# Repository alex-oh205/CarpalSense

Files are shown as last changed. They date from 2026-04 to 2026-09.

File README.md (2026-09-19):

# CarpalSense

Wearable sensor project made by Alex Oh and Arjun ArunPrasad on the software side and Shiv Patel and Kanata Sasaki on the hardware side.

Hardware: A glove that detects and monitors carpal tunnel syndrome using flex sensors, EMG sensors, and an Arduino Nano.
Software: The CarpalSense website, containing detailed usage instructions and a real-time monitoring dashboard displaying the collected data.

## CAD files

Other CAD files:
bme_materials/CarpalSense Glove (Final Product).f3z

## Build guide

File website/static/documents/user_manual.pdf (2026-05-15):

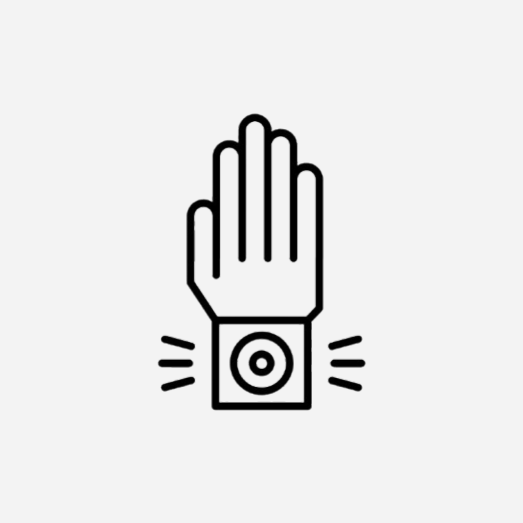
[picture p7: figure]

# CarpalSense Instruction Manual

## Group 3 Wearable Sensor

### Made By: Shiv Patel, Kanata Sasaki, Arjun Arun-Prasad, Alex Oh

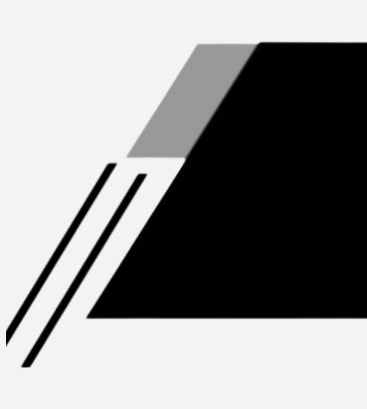
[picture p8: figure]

## Page 01

# Table of Contents

❖Procedure | —--------------------- Page 03
❖Circuit Design | —--------------------- Page 08
❖Fusion Models | —--------------------- Page 09
❖Data | —--------------------- Page 10
➢Flex | —--------------------- | Page 10
➢EMG | —--------------------- Page 11
❖Troubleshooting | —--------------------- Page 12
➢Flex | —--------------------- | Page 12
➢EMG | —--------------------- Page 13

# Procedure

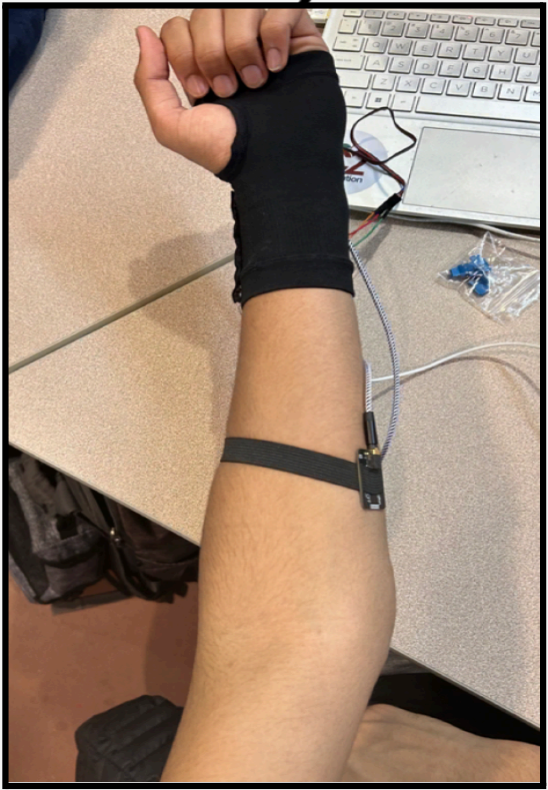
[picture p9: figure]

## Place the EMG sensor on your forearm using the band attached to it. Ensure that the cable is facing away from you and that the EMG is placed on the Flexor Pollicis Longus muscle

Note: This step may require multiple attempts due to the abundance of muscles in the forearm; refer to Troubleshooting for further assistance

Figure 01: Example placement of EMG and proper positioning on forearm

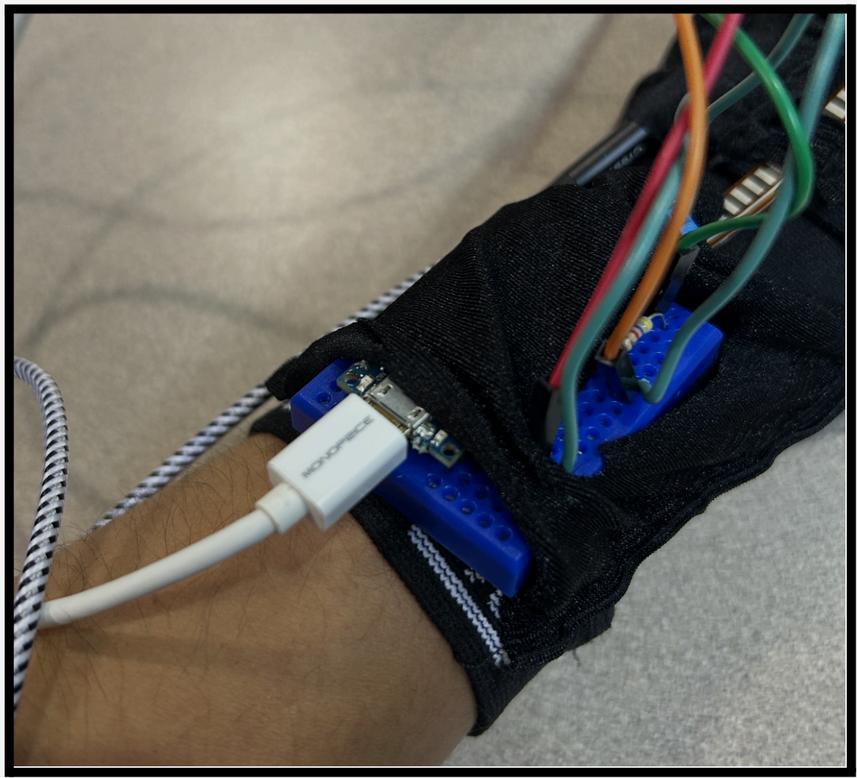
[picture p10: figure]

## Connect a Micro-B to USB cable to the Arduino Nano 33 IOT (located underneath the housing) but do not plug the USB end into the device

being connected.

Figure 02: Micro-B Cable being connected to Arduino Nano

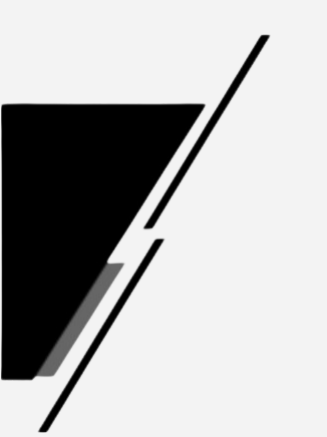
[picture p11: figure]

# Procedure

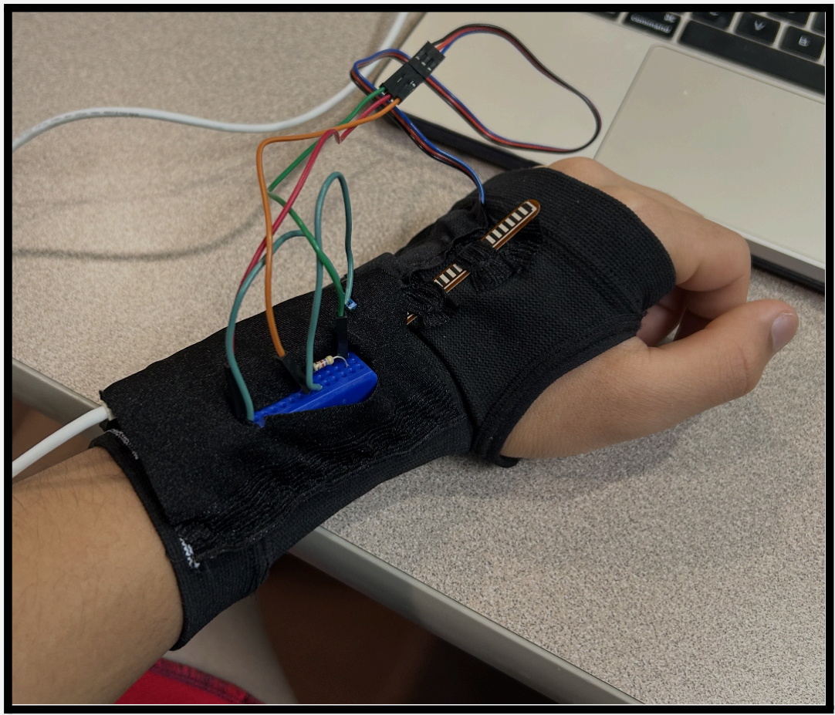
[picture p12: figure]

## Gently pull the glove over your left hand. Make sure that the Arduino 33 Nano IOT and the rest of the circuit are facing up when you do so. Double check all sensor positions before beginning any

data collection.

Figure 03: Wearable sensor fully fitted and worn on the hand.

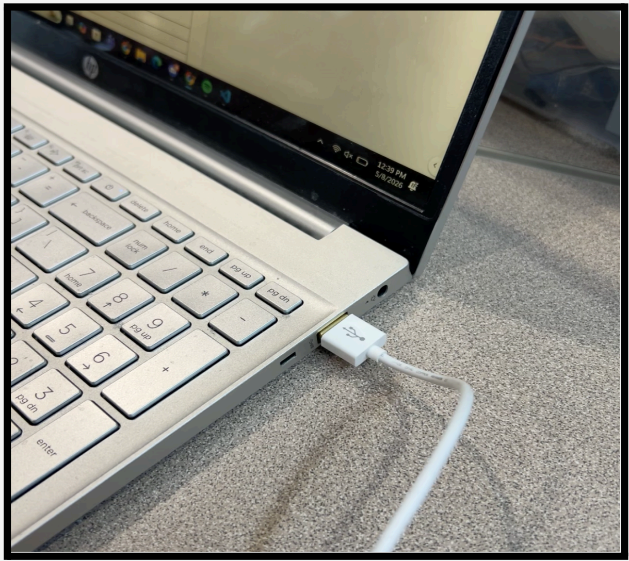
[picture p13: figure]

## Plug in the USB into the computer and place your gloved hand flat on a desk in a flat position for 5-8 seconds. Holding this position will allow the sensor to

calibrate the EMG.

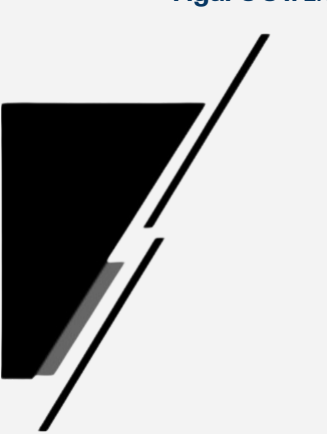
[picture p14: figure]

Figure 04: Example of USB cable connected to a viable device

# Procedure

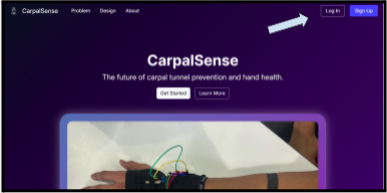
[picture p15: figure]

## Go to the CarpalSense website and log into your account. If you do not have

one, create an account,

## following the prompts given

Figure 05: Homescreen of CarpalSense website with the Log-In page highlighted.

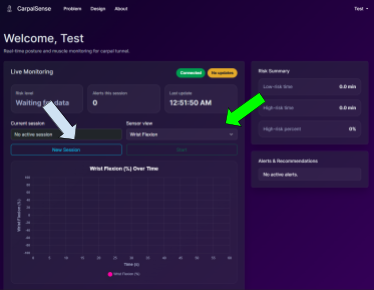
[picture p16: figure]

## Once logged in, select New Session on the Dashboard and click Start to begin collecting data. To toggle which sensor you see, use the drop-down menu

Figure 06: Example Dashboard with the New Session button (blue arrow) and Sensor drop down menu (green arrow) highlighted

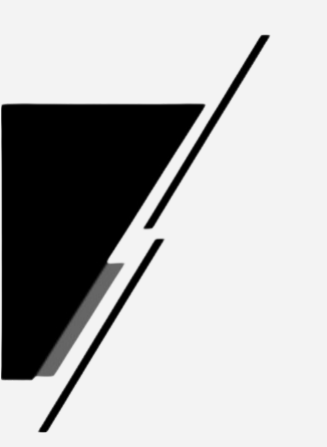
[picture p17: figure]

# Procedure

## After the calibration is complete, all FPL and wrist movement will be monitored and shown on the website via graphs (see Data)

Note: Wrist movements involve bending

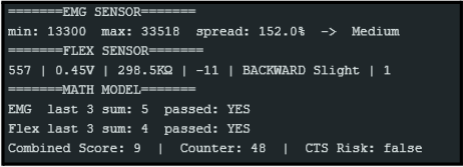
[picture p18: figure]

the wrist forward and backwards and the FPL contractions are monitored by clenching the fist and flexing the muscle

Figure 07: Serial Monitor showing live sensor readings

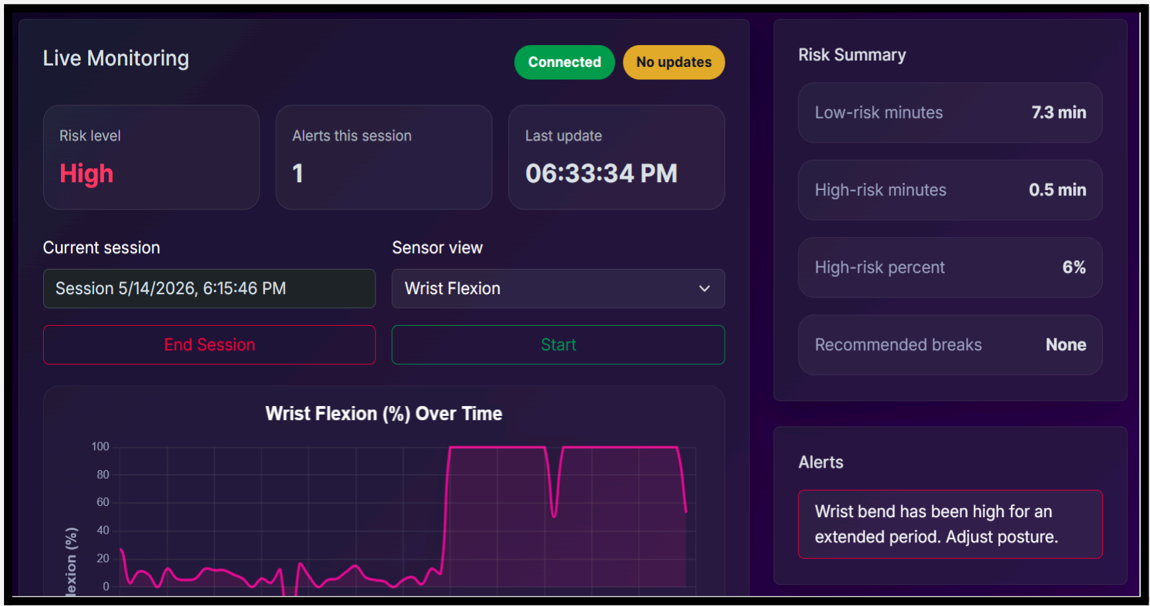
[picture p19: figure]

## If the accumulated strain on the wrist reaches a “danger zone”, a notification will be sent out through the website to tell

you to take a rest.

Figure 08: Alert on website to
show entry into danger zone

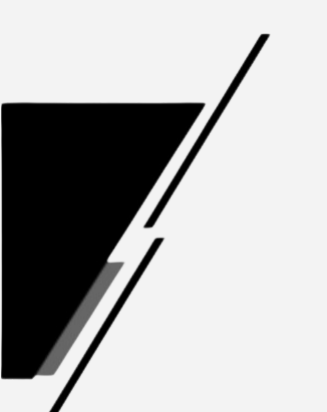
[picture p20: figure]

# Procedure

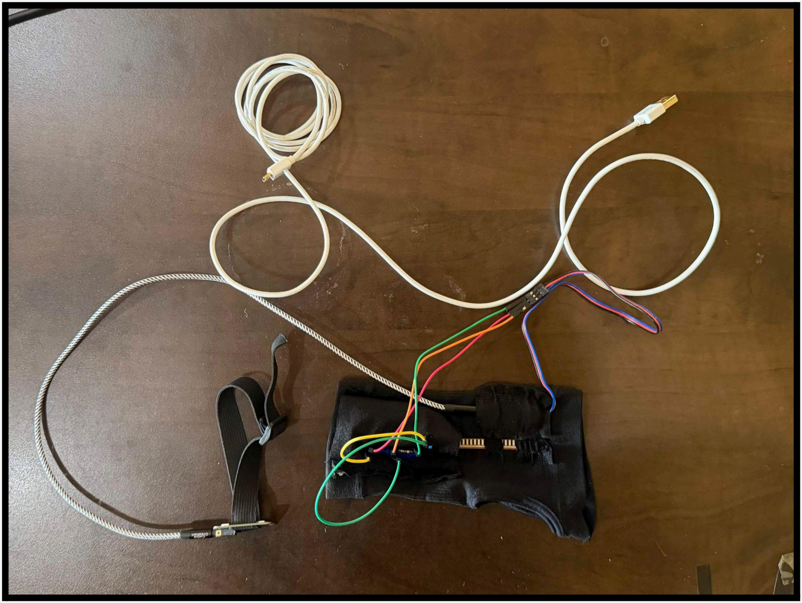
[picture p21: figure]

## To remove the sensor, unplug the Micro-B to USB cable from both ports and then gently remove the glove as well as the Dry EMG band from the forearm. Ensure that no cables are displaced in this process

Figure 09: Safely removed sensor as
well as other components used (cable and band)

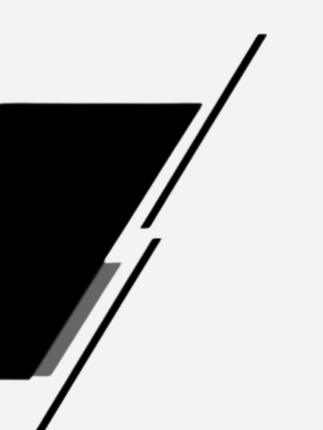
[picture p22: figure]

# Circuit Designs

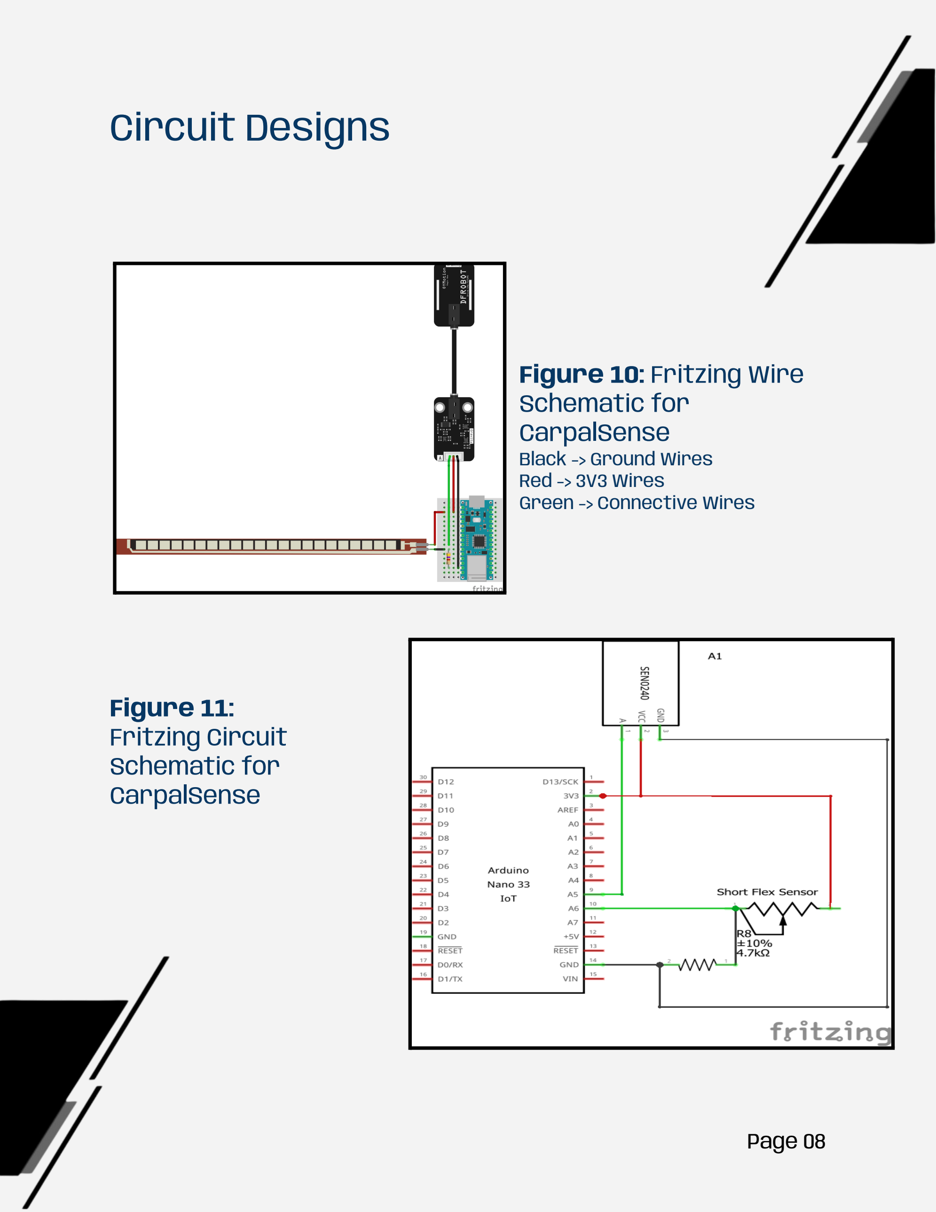
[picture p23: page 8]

## Figure 10: Fritzing Wire Schematic for CarpalSense

### Black -> Ground Wires Red -> 3V3 Wires Green -> Connective Wires

## Figure 11: Fritzing Circuit Schematic for CarpalSense

# Fusion Models

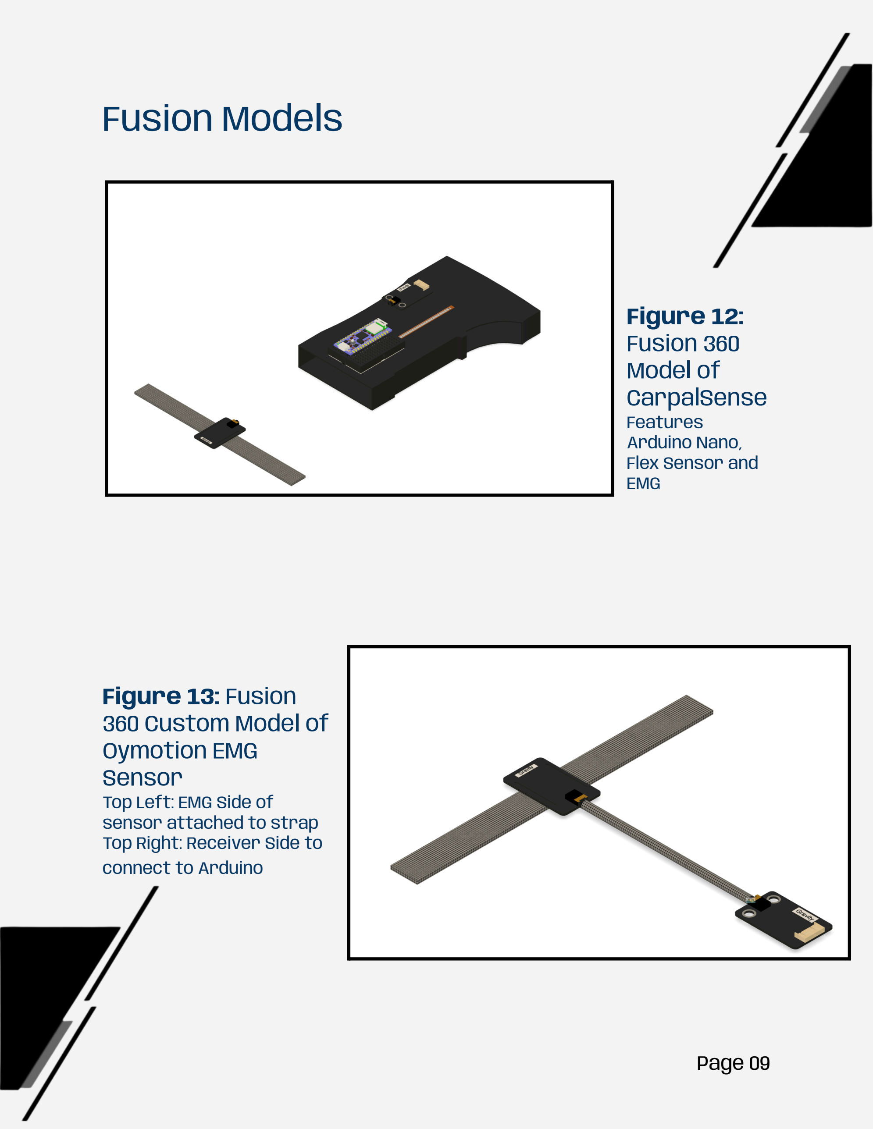
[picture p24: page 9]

## Figure 12: Fusion 360 Model of CarpalSense

### Features

Arduino Nano,

### Flex Sensor and EMG

## Figure 13: Fusion 360 Custom Model of Oymotion EMG Sensor

### Top Left: EMG Side of sensor attached to strap Top Right: Receiver Side to connect to Arduino

# Data

# Flex

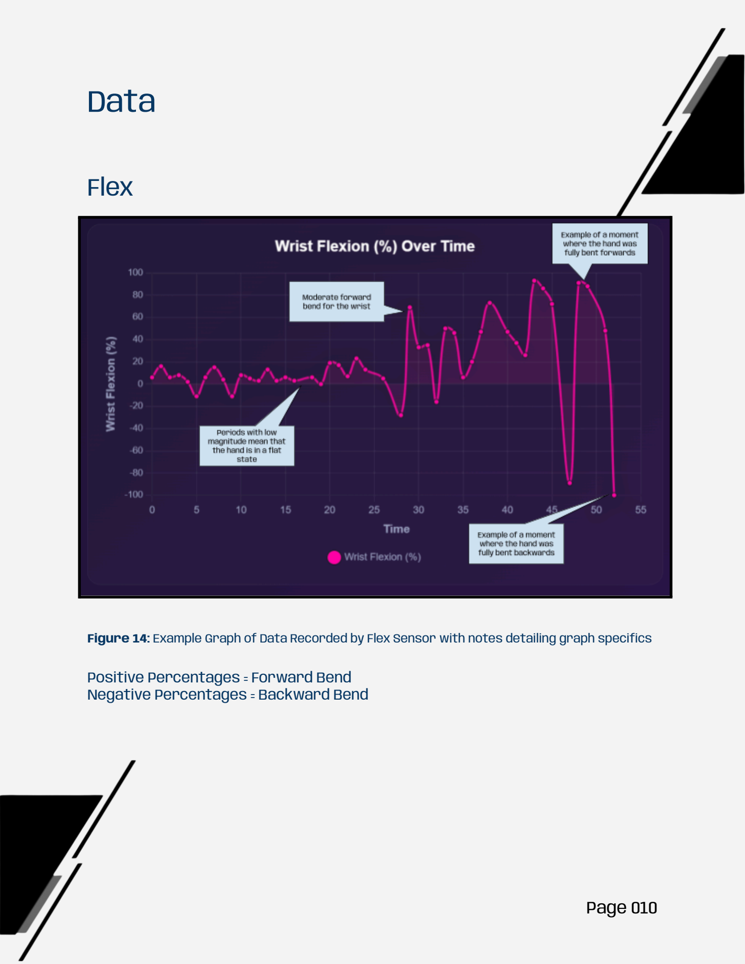
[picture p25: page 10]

Figure 14: Example Graph of Data Recorded by Flex Sensor with notes detailing graph specifics

### Positive Percentages = Forward Bend Negative Percentages = Backward Bend

# Data

# EMG

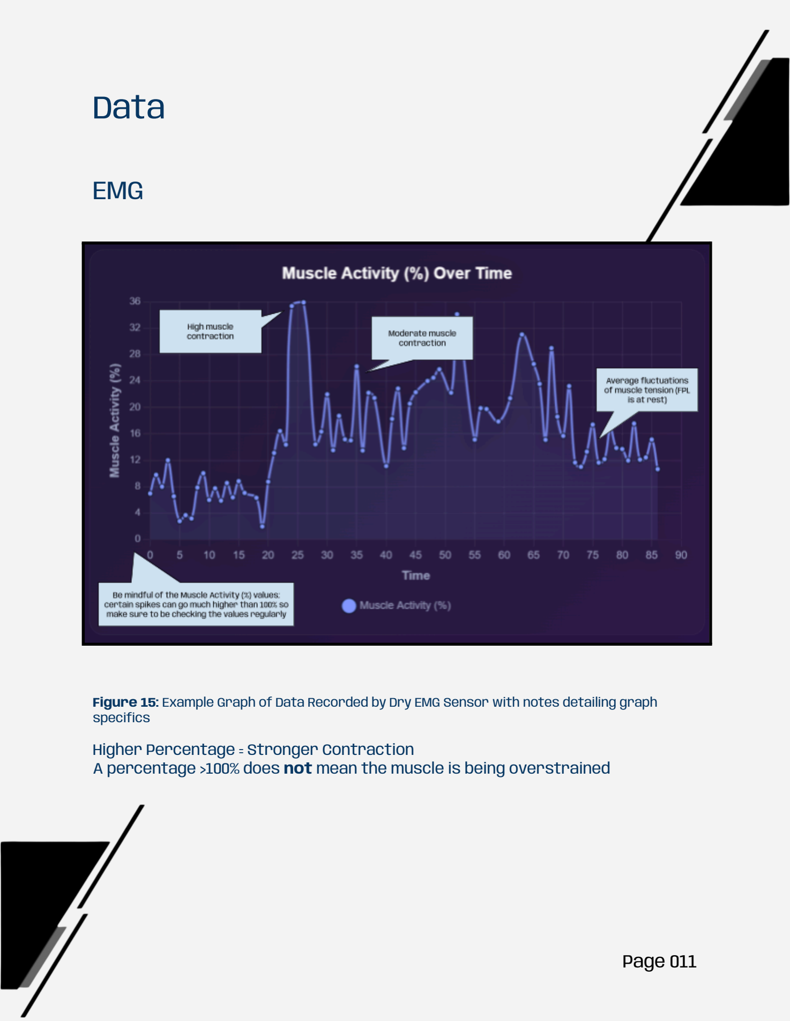
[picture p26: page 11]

Figure 15: Example Graph of Data Recorded by Dry EMG Sensor with notes detailing graph specifics

### Higher Percentage = Stronger Contraction A percentage >100% does not mean the muscle is being overstrained

# Troubleshooting

# Flex

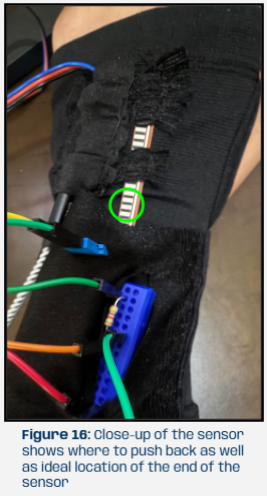
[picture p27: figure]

## ❖Bending not recording

### - Double check all wires and make sure they are connected

■ Wires will connect to the Clinch Connector inside of the housing, not the flex sensor itself

### - Check the flex sensor’s position

■ The end of the sensor should be pushed as far in as it can go.
■ If the sensor is not fully pushed in, gently push it further in at the position specified by the green circle on Figure 15.

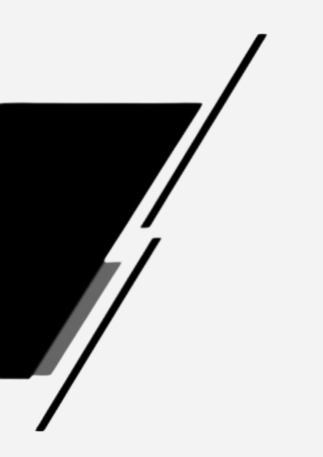
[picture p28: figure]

# Troubleshooting

# EMG

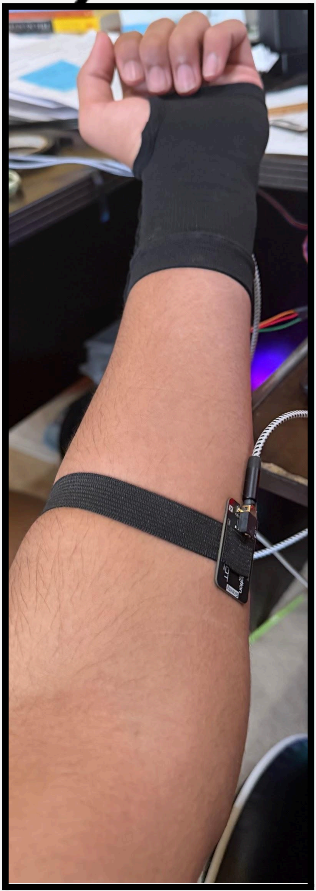
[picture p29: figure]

## ❖Contractions not recording

### - Check to see if EMG sensor is placed on the right muscle body

■ Place your arm palm up and clench your fist repeatedly ■ Feel along the side of your forearm until you find a muscle that is tensing with your forearm. Place EMG there.

### - Make sure all wires are connected properly to the sensors - Tighten EMG sensor on the muscle body

## ❖Constantly Returning “High” Contractions

### - Restart the program

■ Unplug the sensor and plug it back in
■ This will recalibrate the baseline

### - Double check EMG placement on the forearm

■ Incorrect placement of the EMG can cause it to read multiple muscles at once or pick up on unnecessary noise ■ View placement directions above

## ❖General Debugging

### - Bicep Check

■ If there are concerns with the EMG sensor, place the
sensor on your bicep and monitor the contractions
following the same procedure as before
■ If the contractions align with bicep motions, it is most likely a placement error
■ If the contractions do not align, check all wires connections to make sure the EMG is properly connected

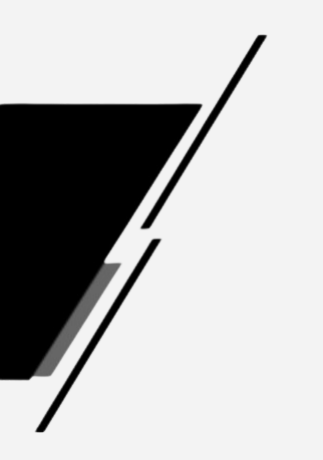
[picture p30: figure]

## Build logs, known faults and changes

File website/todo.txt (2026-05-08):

- Change Firebase data structure to include date/time
- Make it so you can select a date/time to view its data
- Footer

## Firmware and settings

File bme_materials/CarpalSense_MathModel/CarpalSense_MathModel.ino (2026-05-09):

// ============================================================
// CarpalSense — Full Integrated Math Model
// Arduino Nano 33 IoT
//
// SENSORS:
//   Flex sensor → A6
//   EMG sensor  → A5
//
// OUTPUT:
//   Serial Monitor only (no buzzer)
//
// WHAT THIS DOES:
//   1. Reads flex sensor → converts to 0-3 score
//   2. Calibrates EMG baseline on startup (30 seconds)
//   3. Reads EMG sensor → converts to 0-3 score
//   4. Combines both into Cumulative Strain Score (CSS)
//   5. Prints full dashboard to Serial Monitor every second
//
// SCIENTIFIC BASIS:
//   Flex thresholds: 25mmHg carpal tunnel pressure research
//     Forward (flexion)  danger at 38° → position ~+65
//     Backward (extension) danger at 27° → position ~-50
//   EMG thresholds: intramuscular pressure research
//     4x resting baseline ≈ 25% MVC ≈ 21mmHg pressure
//   CSS weights: force (EMG) weighted higher than posture (flex)
//     based on pooled study of 2,474 workers
//   CSS thresholds: Revised Strain Index clinical research
//     Safe < 8.5, Caution 8.5-15, Warning 15-20, Danger > 20
// ============================================================


// ============================================================
// FLEX SENSOR SETUP
// Copied directly from your existing code
// ============================================================
const int   FLEX_PIN    = A6;
const float VCC         = 3.3;
const float R_DIV       = 47000.0;

// Your calibrated raw values — keep these as they are
int rawFlat     = 22;
int rawForward  = 7;
int rawBackward = 40;

const int DEADZONE = 2;

// ------------------------------------------------------------
// FLEX POSITION THRESHOLDS
// These are in "position" units (-100 to +100) from your code
//
// FORWARD  = wrist flexion  (danger at 38°)
// BACKWARD = wrist extension (danger at 27°)
//
// Your position scale goes 0 to 100 for full bend.
// 38° flexion is roughly 65% of your full forward range.
// 27° extension is roughly 50% of your full backward range.
//
// So in position units:
//   Forward  warn    = +40   (approaching 38° flexion)
//   Forward  danger  = +65   (at 38° flexion)
//   Backward warn    = -35   (approaching 27° extension)
//   Backward danger  = -50   (at 27° extension)
//
// IF THESE FEEL WRONG after testing, adjust them here.
// ------------------------------------------------------------
const int FLEX_FWD_WARN    =  40;
const int FLEX_FWD_DANGER  =  65;
const int FLEX_BWD_WARN    = -35;
const int FLEX_BWD_DANGER  = -50;


// ============================================================
// EMG SENSOR SETUP
// ============================================================
const int EMG_PIN = A5;

// Calibration
const int CALIBRATION_SECONDS = 30;
float     emgBaseline         = 0.0;
bool      calibrated          = false;

// EMG ratio thresholds (multiples of resting baseline)
// 2x = light sustained effort  (~5% MVC)
// 3x = moderate effort         (~10-15% MVC)
// 4x = high effort             (~20-25% MVC)
//      Research: 25% MVC produces 21mmHg intramuscular pressure
//      approaching your 25mmHg clinical CTS threshold
const float EMG_LEVEL_1 = 2.0;
const float EMG_LEVEL_2 = 3.0;
const float EMG_LEVEL_3 = 4.0;


// ============================================================
// CSS (CUMULATIVE STRAIN SCORE) SETUP
// Thresholds from Revised Strain Index clinical research
// validated on 1,372 workers followed for up to 6 years
// ============================================================
float css = 0.0;

const float CSS_CAUTION  =  8.5;
const float CSS_WARNING  = 15.0;
const float CSS_DANGER   = 20.0;

// Weights — EMG carries more weight than flex
// Scientific basis: forceful exertion is a stronger
// independent predictor of CTS than wrist posture alone
const float EMG_WEIGHT   = 0.6;
const float FLEX_WEIGHT  = 0.4;

// Recovery rate when both sensors read 0
// Muscles recover slowly — not instant
const float RECOVERY_RATE = 0.1;


// ============================================================
// TIMING
// ============================================================
unsigned long previousMillis = 0;
const long    INTERVAL       = 1000; // update every 1 second


// ============================================================
// SETUP
// ============================================================
void setup() {
  Serial.begin(9600);
  while (!Serial);

  pinMode(FLEX_PIN, INPUT);

  Serial.println("============================================");
  Serial.println("        CarpalSense Starting Up            ");
  Serial.println("============================================");

  // Run EMG calibration before anything else
  calibrateEMG();
}


// ============================================================
// MAIN LOOP
// ============================================================
void loop() {
  unsigned long currentMillis = millis();

  if (currentMillis - previousMillis >= INTERVAL) {
    previousMillis = currentMillis;

    // 1. Get flex position and score
    int flexPosition = getFlexPosition();
    int flexScore    = getFlexScore(flexPosition);

    // 2. Get EMG score
    int emgScore = getEMGScore();

    // 3. Update CSS
    updateCSS(flexScore, emgScore);

    // 4. Print full dashboard
    printDashboard(flexScore, emgScore, flexPosition);
  }
}


// ============================================================
// EMG CALIBRATION
// Runs once on startup for 30 seconds.
// User must rest hand flat on desk doing nothing.
// Averages thousands of readings for accurate baseline.
// ============================================================
void calibrateEMG() {
  Serial.println("CALIBRATION STARTING IN 3 SECONDS...");
  Serial.println("Rest your hand flat on the desk. Do not move.");
  delay(3000);
  Serial.println("Calibrating...");

  long  total      = 0;
  int   samples    = 0;
  int   lastPrint  = 0;
  unsigned long startTime = millis();

  while (millis() - startTime < (CALIBRATION_SECONDS * 1000UL)) {
    total += analogRead(EMG_PIN);
    samples++;

    int elapsed = (millis() - startTime) / 1000;
    if (elapsed % 5 == 0 && elapsed != lastPrint && elapsed > 0) {
      Serial.print(CALIBRATION_SECONDS - elapsed);
      Serial.println(" seconds remaining...");
      lastPrint = elapsed;
    }
    delay(10);
  }

  emgBaseline = (float)total / samples;
  calibrated  = true;

  Serial.println("--------------------------------------------");
  Serial.print("Baseline set: ");
  Serial.println(emgBaseline, 1);
  Serial.println("Monitoring started.");
  Serial.println("============================================");
  Serial.println("Flex | EMG | CSS    | Risk");
  Serial.println("============================================");
}


// ============================================================
// FLEX POSITION
// Copied directly from your existing code.
// Returns -100 (full backward) to +100 (full forward)
// ============================================================
int getFlexPosition() {
  int   raw     = analogRead(FLEX_PIN);
  float voltage = raw * (VCC / 1023.0);
  float resistance = 0;

  if (voltage > 0) {
    resistance = R_DIV * (VCC / voltage - 1.0);
  }

  int position = 0;

  if (raw < rawFlat - DEADZONE) {
    // Bending FORWARD (flexion)
    position = constrain(
      (int)((rawFlat - raw) / (float)(rawFlat - rawForward) * 100.0),
      0, 100
    );
  } else if (raw > rawFlat + DEADZONE) {
    // Bending BACKWARD (extension)
    position = constrain(
      (int)((raw - rawFlat) / (float)(rawBackward - rawFlat) * 100.0),
      0, 100
    ) * -1;
  }

  return position;
}


// ============================================================
// FLEX SCORE (0-3)
// Converts position (-100 to +100) into risk score.
//
// Score meaning:
//   0 = neutral, no risk
//   1 = slight bend, minor risk
//   2 = moderate bend, approaching clinical danger angle
//   3 = severe bend, past clinical danger angle
//
// Clinical basis (25mmHg threshold):
//   Flexion danger at 38°   → mapped to position +65
//   Extension danger at 27° → mapped to position -50
// ============================================================
int getFlexScore(int position) {

  // Forward = wrist flexion
  if (position > DEADZONE) {
    if (position >= FLEX_FWD_DANGER) return 3;
    if (position >= FLEX_FWD_WARN)   return 2;
    return 1;
  }

  // Backward = wrist extension
  if (position < -DEADZONE) {
    if (position <= FLEX_BWD_DANGER) return 3;
    if (position <= FLEX_BWD_WARN)   return 2;
    return 1;
  }

  // Neutral
  return 0;
}


// ============================================================
// EMG SCORE (0-3)
// Compares current reading to resting baseline.
//
// Score meaning:
//   0 = at or below baseline (resting)
//   1 = 2x baseline, light sustained effort (~5% MVC)
//   2 = 3x baseline, moderate effort (~10-15% MVC)
//   3 = 4x+ baseline, high effort (~20-25% MVC)
//       At 25% MVC intramuscular pressure reaches 21mmHg
//       approaching your 25mmHg clinical CTS threshold
// ============================================================
int getEMGScore() {
  if (!calibrated) return 0;

  float raw   = analogRead(EMG_PIN);
  float ratio = raw / emgBaseline;

  if (ratio >= EMG_LEVEL_3) return 3;
  if (ratio >= EMG_LEVEL_2) return 2;
  if (ratio >= EMG_LEVEL_1) return 1;
  return 0;
}


// ============================================================
// UPDATE CSS
// Adds weighted sensor scores every second.
// Slowly recovers when both sensors read 0.
//
// Formula every second:
//   CSS += (emgScore x 0.6) + (flexScore x 0.4)
//
// Weight rationale:
//   EMG (force/effort) = stronger CTS predictor
//   Flex (posture)     = real but weaker predictor
//   Source: pooled biomechanical study of 2,474 workers
// ============================================================
void updateCSS(int flexScore, int emgScore) {
  if (flexScore == 0 && emgScore == 0) {
    // Both sensors clear — gradual recovery
    css -= RECOVERY_RATE;
    if (css < 0) css = 0;
  } else {
    float contribution = (emgScore * EMG_WEIGHT) + (flexScore * FLEX_WEIGHT);
    css += contribution;
  }
}


// ============================================================
// PRINT DASHBOARD
// Prints one clean row per second to Serial Monitor.
// Includes direction and zone from your original flex code.
// ============================================================
void printDashboard(int flexScore, int emgScore, int flexPosition) {

  // Flex direction label from your original code
  const char* direction;
  const char* zone;

  if (flexPosition > DEADZONE) {
    direction = "FORWARD ";
    if      (flexPosition < 30) zone = "Slight  ";
    else if (flexPosition < 65) zone = "Moderate";
    else                        zone = "Full    ";
  } else if (flexPosition < -DEADZONE) {
    direction = "BACKWARD";
    if      (flexPosition > -30) zone = "Slight  ";
    else if (flexPosition > -65) zone = "Moderate";
    else                         zone = "Full    ";
  } else {
    direction = "FLAT    ";
    zone      = "        ";
  }

  // Risk level from CSS thresholds
  const char* riskLevel;
  const char* message;

  if (css < CSS_CAUTION) {
    riskLevel = "SAFE   ";
    message   = "All clear.";
  } else if (css < CSS_WARNING) {
    riskLevel = "CAUTION";
    message   = "Strain accumulating. Take a break soon.";
  } else if (css < CSS_DANGER) {
    riskLevel = "WARNING";
    message   = "High strain. Stop and rest now.";
  } else {
    riskLevel = "DANGER ";
    message   = "STOP IMMEDIATELY. Serious CTS risk.";
  }

  // Print full row
  Serial.print("Flex:");
  Serial.print(flexScore);
  Serial.print(" (");
  Serial.print(direction);
  Serial.print(" ");
  Serial.print(zone);
  Serial.print(") | EMG:");
  Serial.print(emgScore);
  Serial.print(" | CSS:");
  Serial.print(css, 2);
  Serial.print(" | ");
  Serial.print(riskLevel);
  Serial.print(" | ");
  Serial.println(message);
}

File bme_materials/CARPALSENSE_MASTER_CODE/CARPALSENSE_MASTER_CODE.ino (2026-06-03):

//  SECTION 1: LIBRARIES AND VARIABLES

// Arduino Libraries
#include "Arduino.h"
#include <limits.h>       // used for window timing
#include "EMGFilters.h"   // needed for EMG code

// Flex Pins
const int   FLEX_PIN = A6;
const float FLEX_VCC = 3.3;
const float FLEX_RES = 47000.0;

// Flex Thresholds
int flexFlat = 550;  // flat value
int flexForward = 400;  // fully bent forward
int flexBackward = 600;  // fully bent backward

const int flexDead = 2;
int returnValue = 0;     // Flex: 0 = None to 3 = High
int level = 0;           // EMG: 0 = No Contraction to 3 = High Contraction

// EMG Pins + RMS
#define SensorInputPin A5
#define RMS_WINDOW 100

long emgBuffer[RMS_WINDOW] = {0};   
int  emgIndex = 0;
long emgRMS = 0;

// EMG Filter
EMGFilters myFilter;
SAMPLE_FREQUENCY sampleRate = SAMPLE_FREQ_500HZ;
NOTCH_FREQUENCY  humFreq    = NOTCH_FREQ_60HZ;

// EMG Thresholds
const unsigned long emgWindow = 1000;  // length of each observation window in milliseconds
const float emgLow = 50.0f;           
const float emgMedium = 100.0f;
const float emgHigh = 200.0f;

unsigned long windowStart = 0;         // Records the time between each EMG return
long windowMin = LONG_MAX;
long windowMax = 0;

// Math Model Values
long ctsCounter = 0;          // total weighted score
const long ctsThreshold = 500000;      // threshold to alert user of CTS risk
bool ctsRisk = false;

int emgMM[3] = {0, 0, 0};   // array of the last 3 readings for EMG
int flexMM[3] = {0, 0, 0};   // array of the last 3 readings for flex
int historyIndex = 0;
bool historyFull = false;
const int valueThreshold = 4; // minimum value of the combined three readings to filter out spikes


//  SECTION 2: SENSOR CODE
// EMG RMS
long computeRMS(long newVal) {        // function is used to smooth out values from EMG sensor
    if (newVal > 200000) newVal = 200000;
    emgRMS -= emgBuffer[emgIndex];
    emgBuffer[emgIndex] = newVal;
    emgRMS += newVal;
    emgIndex = (emgIndex + 1) % RMS_WINDOW;
    return emgRMS / RMS_WINDOW;
}

void setup() {
    // EMG Setup
    analogReference(AR_DEFAULT);
    analogReadResolution(12);
    myFilter.init(sampleRate, humFreq, true, true, true);
    Serial.begin(9600);
    delay(1000);

    for (int i = 0; i < 2000; i++) {          // repeats EMG collection multiple times per loop
        analogRead(SensorInputPin);
        int Value = analogRead(SensorInputPin);
        myFilter.update(Value - 3700);
        delayMicroseconds(2000);
    }

    // Flex Setup
    pinMode(FLEX_PIN, INPUT);     // gathers data from flex
    // Setup Notification
    Serial.println("CTS Master Sensor Code");
    Serial.println("EMG ready. Flex sensor ready.");
    windowStart = millis();
}

void loop() {

    // EMG Data
    analogRead(SensorInputPin);
    int emgRet = analogRead(SensorInputPin);
    int centered  = emgRet - 3700;           // clears out extra noise
    int filtered  = myFilter.update(centered);
    long envelope = (long)filtered * filtered;
    long smoothed = computeRMS(envelope);

    if (smoothed < windowMin) windowMin = smoothed;
    if (smoothed > windowMax) windowMax = smoothed;

    // Flex Data
    int flexRaw = analogRead(FLEX_PIN);
    int flexPosition = 0;
    if (flexRaw < flexFlat - flexDead) {
        flexPosition = constrain(
            (int)((flexFlat - flexRaw) / (float)(flexFlat - flexForward) * 100.0),
            0, 100
        );
    } else if (flexRaw > flexFlat + flexDead) {
        flexPosition = constrain(
            (int)((flexRaw - flexFlat) / (float)(flexBackward - flexFlat) * 100.0),
            0, 100
        ) * -1;
    }

    const char* flexDirection;
    const char* flexBend;

    if (flexPosition > flexDead) {   // uses positive and negative raw values to determine flexion/extension and assigns a value to the returnValue to be used in the math model
        flexDirection = "FORWARD";
        if (flexPosition < 40) { flexBend = "Slight";   returnValue = 1; }
        else if (flexPosition < 75) { flexBend = "Moderate"; returnValue = 2; }
        else { flexBend = "Full";      returnValue = 3; }
    } else if (flexPosition < -flexDead) {    // different values are used for backwards because backwards movement is more strenuous
        flexDirection = "BACKWARD";
        if (flexPosition > -30) { flexBend = "Slight";   returnValue = 1; }
        else if (flexPosition > -55) { flexBend = "Moderate"; returnValue = 2; }
        else { flexBend = "Full";      returnValue = 3; }
    } else {
        flexDirection = "FLAT";
        flexBend      = "";
        returnValue    = 0;
    }

    unsigned long now = millis();
    if (now - windowStart >= emgWindow) {
        float pct = 0.0f;
        if (windowMin > 0) {
            pct = ((float)(windowMax - windowMin) / (float)windowMin) * 100.0f;
            if (pct >= emgHigh) level = 3;
            else if (pct >= emgMedium) level = 2;
            else if (pct >= emgLow)  level = 1;
            else level = 0;
        }

        Serial.println("EMG SENSOR");
        Serial.print("min: " + String(windowMin)); 
        Serial.print("  max: " + String(windowMax)); 
        Serial.print("  spread: " + String(pct) + "1"); 
        Serial.print("% ->  ");
        switch (level) {
            case 0: Serial.println("No Contraction"); break;
            case 1: Serial.println("Low"); break;
            case 2: Serial.println("Medium"); break;
            case 3: Serial.println("High"); break;
            default: Serial.println("Error"); break;
        }
        Serial.println("FLEX SENSOR");
        Serial.print("Raw: " + String(flexRaw));
        Serial.print(" | " + String(flexPosition)); 
        Serial.print(" | " + String(flexDirection)); 
        Serial.print(" | Bend: " + String(flexBend)); 
        Serial.println(" | Filter Value: " + String(returnValue)); 

        // Math model
        emgMM[historyIndex]  = level;
        flexMM[historyIndex] = returnValue;
        historyIndex = (historyIndex + 1) % 3;      // resets array every 3 loops 
        if (historyIndex == 0) historyFull = true;  

        int combinedScore = 0;
        bool emgCounter  = false;
        bool flexCounter = false;

        if (historyFull && historyIndex == 0) {    // compares 3 stored values to the threshold after 3 trials
            int emgSum  = emgMM[0]  + emgMM[1]  + emgMM[2];
            int flexSum = flexMM[0] + flexMM[1] + flexMM[2];
            if (emgSum  >= valueThreshold) { combinedScore += emgSum;  emgCounter  = true; }
            if (flexSum >= valueThreshold) { combinedScore += flexSum; flexCounter = true; }

            ctsCounter += combinedScore;
        }

        if (ctsCounter >= ctsThreshold) ctsRisk = true;
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

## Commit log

2025-12-17 Replaced old Fritzer file with new one
    [CarpelSense Fritz (FIN).fzz, CarpelSense Fritz.fzz]
2025-12-21 Fixed Fritzer
    [CarpelSense Fritz (FIN).fzz]
2026-01-21 Carpal Sense Fusion 360
    Fusion design for Group 3 Wearable Sensor
    [CarpelSense Fusion 360.f3z]
2026-01-28 Create Patel Vibrational Buzzer v1.f3d
    [Patel Vibrational Buzzer v1.f3d]
2026-02-11 2/11/2026 - Commit 1
    Set up flask
    [CarpelSense Fritz (FIN).fzz, CarpelSense Fusion 360.f3z, Patel Vibrational Buzzer v1.f3d]
2026-02-27 Added Flask demo code
    1. HTML files
    2. JS files
    3. Python communication with Arduino
    4. Firebase config
2026-03-04 3/4/2026 - Commit 1
    1. Updated app.py to include register and sign in routes
    2. Fixed the sign in button not going to the dashboard page
2026-03-04 Added Arduino file
2026-03-11 Fixed Flex Sensor
    Fixed the code for the flex sensor and put it inside the apiTest ino
    [apiTest.ino]
2026-04-06 Revised sensor codes
2026-04-06 Redid Carpal Sense Glove Fusion
    [CarpalSense Glove v2.f3z]
2026-04-29 4/29/2026 - Commit 2
    1. Created materials paragraph and started bill of materials on design.html
    2. Styled design.html
2026-04-30 Update CarpelSense Fritz (FIN).fzz
    [CarpelSense Fritz (FIN).fzz]
2026-05-01 Fusion revision
    Primary fusion was redone to include a dry emg. Fritzer was also changed to account for new emg
    [CarpalSense Glove v2.f3z, CarpalSense Glove.f3z, CarpelSense Fritz (FIN).fzz]
2026-05-04 5/4/2026 - Commit 1
    design.html:
    1. Rendered 3D model of sensor on website
    2 .Fixed bug where website wasn’t loading
    3. Embedded future usage instructions video into design.html (placeholder video file)
2026-05-06 Code Alterations
    Changed thresholds for flex sensor and tested emg code
    [emg.ino]
2026-05-06 Design / About pages
    Fixed about card spacing
    FInished BoM design page
2026-05-08 Flex sensor revision
    Now counts movements backwards
    [biflex_sensor.ino]
2026-05-09 Created Master Code
    Utilized bases from Math model as well as revised some parts of the EMG code and created a master code that includes the flex and emg sensors as well as the math model for processing them all
    [CARPALSENSE_MASTER_CODE.ino, CarpalSense_MathModel.ino, oymotion_emg.ino]
2026-05-09 Revised Code and Models
    Redid Fusion and Fritzing models as well as implemented a filter mechanism into the master code
    [CarpalSense Glove (Final Product).f3z, CarpalSense Glove.f3z, CarpelSense Fritz (FIN).fzz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]
2026-05-13 Fixed error in flex sensor
    Moved a semicolon
    [biflex_sensor.ino]
2026-05-13 Changed thresholds for sensors
    New EMG thresholds and new flex thresholds to match the new sensor
    [CARPALSENSE_MASTER_CODE.ino, apiTest.ino, biflex_sensor.ino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]
2026-05-14 Sensor works
2026-05-29 Removed unneeded lines
    Some prints and variables that were leftover from debugging the sensor were removed and the code was organized to be more readable
2026-06-03 Code Error Fixed
    There were errors in the last minute code that I changed and I had to debug them.
    [CARPALSENSE_MASTER_CODE.ino, apiTest.ino]
